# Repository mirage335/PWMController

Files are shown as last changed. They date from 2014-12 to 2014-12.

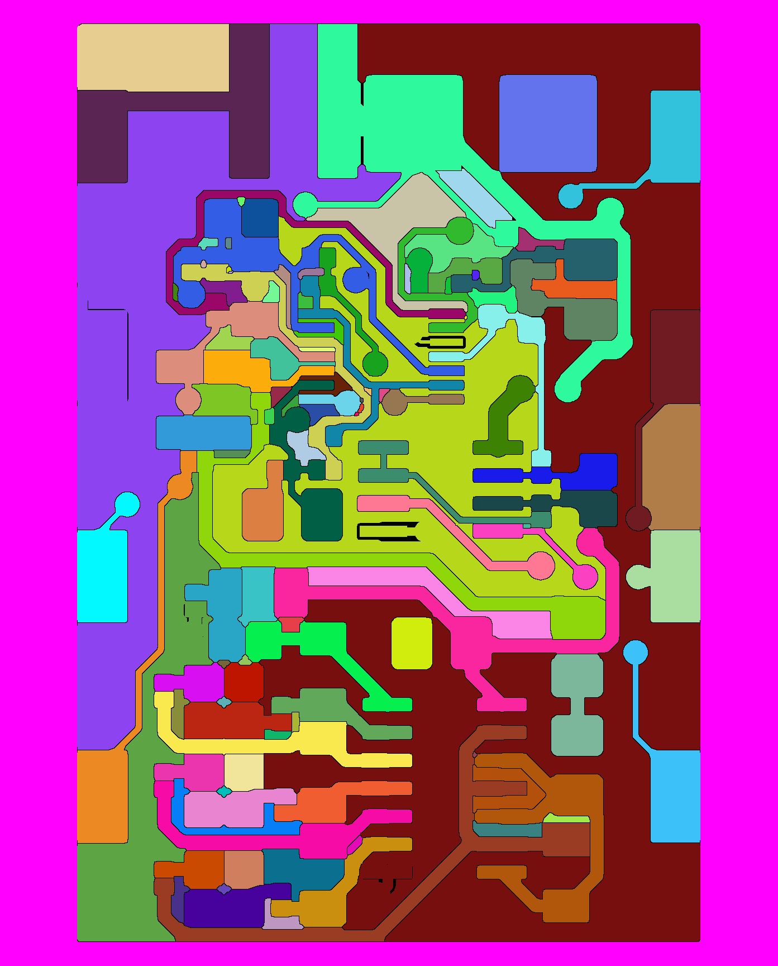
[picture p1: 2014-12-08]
productionStatic/hacdcCNC/PWMController/outp7_traced.png

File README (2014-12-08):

Copyright (C) 2014 mirage335
See the end of the file for license conditions.
See license.txt for PWMController license conditions.

__Usage__
Generic switching power supply block, with emphasis on low EMI. Capable of self-bootstrapping, may be used to generate control voltages for MOSFETS, IGBTs, and similar devices. In some situations, particularly with a linear regulator, may be directly suitable as a generic power supply.

Top-level schematic and PCB layout form a dedicated PCB module, which may be surface-mount soldered directly to the pads defined in the subcircuit. Subcircuit may be integrated into other systems, where individual components or entire module may be soldered in place.

__Design__
Spread-spectrum low-frequency (~5kHz default) switching power supply regulator. Modulation has been carefully characterized to minimize narrowband interference. Duty cycle is limited to permit flyback converter use.

USA companies provide all parts in these schematics.

__Safety__

__Copyright__
This file is part of PWMController.

PWMController is free software: you can redistribute it and/or modify
it under the terms of the GNU General Public License as published by
the Free Software Foundation, either version 3 of the License, or
(at your option) any later version.

PWMController is distributed in the hope that it will be useful,
but WITHOUT ANY WARRANTY; without even the implied warranty of
MERCHANTABILITY or FITNESS FOR A PARTICULAR PURPOSE.  See the
GNU General Public License for more details.

You should have received a copy of the GNU General Public License
along with PWMController.  If not, see <http://www.gnu.org/licenses/>.

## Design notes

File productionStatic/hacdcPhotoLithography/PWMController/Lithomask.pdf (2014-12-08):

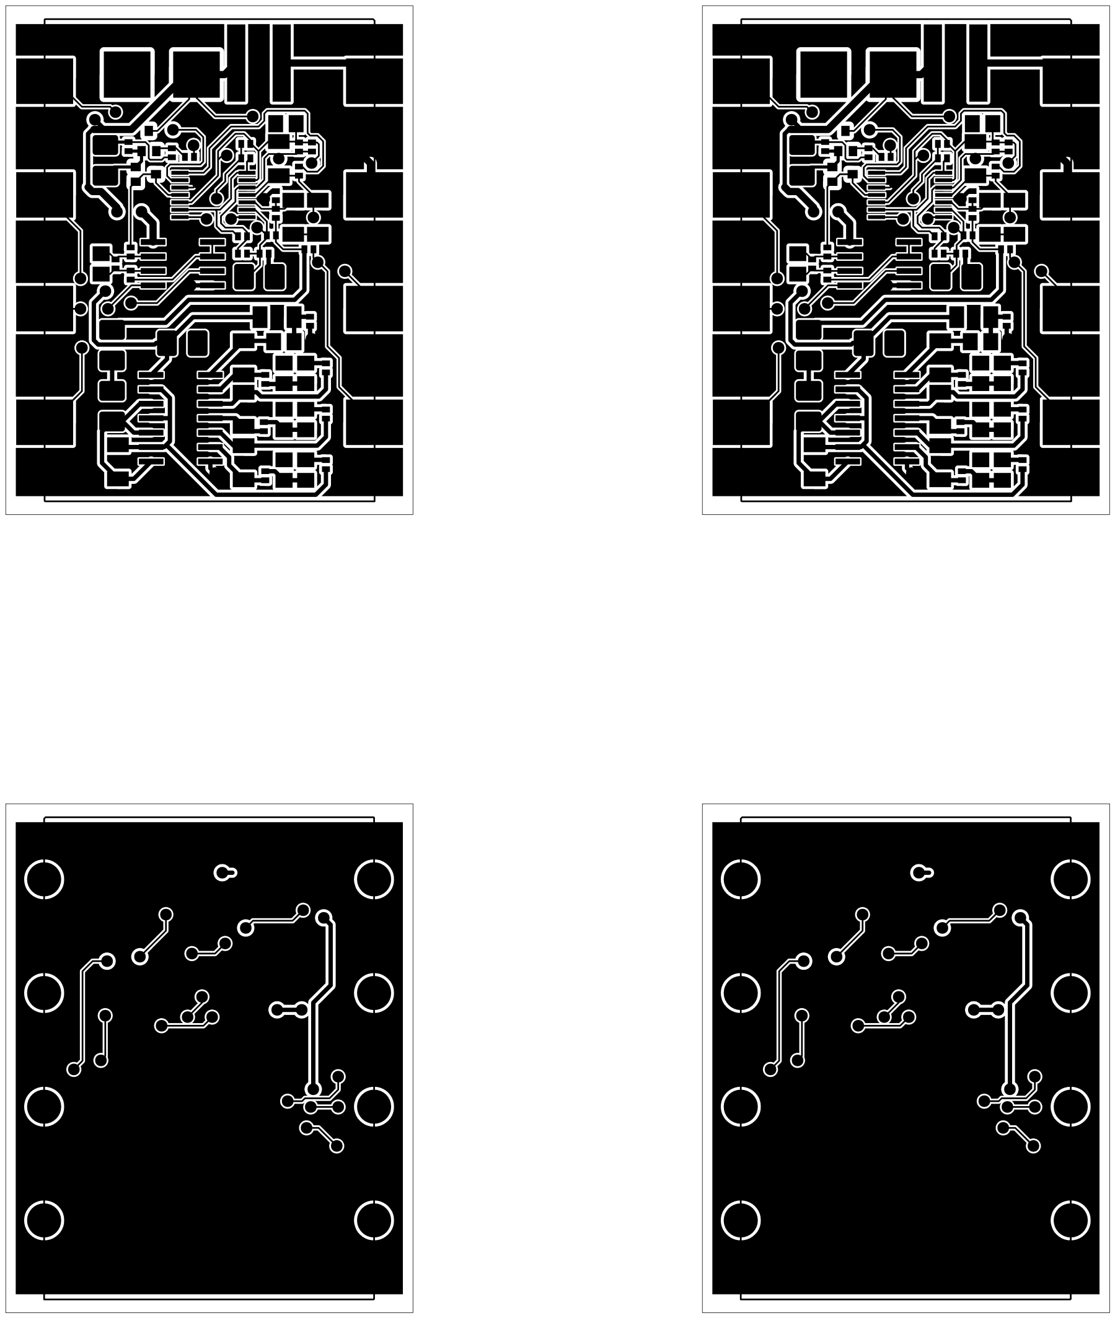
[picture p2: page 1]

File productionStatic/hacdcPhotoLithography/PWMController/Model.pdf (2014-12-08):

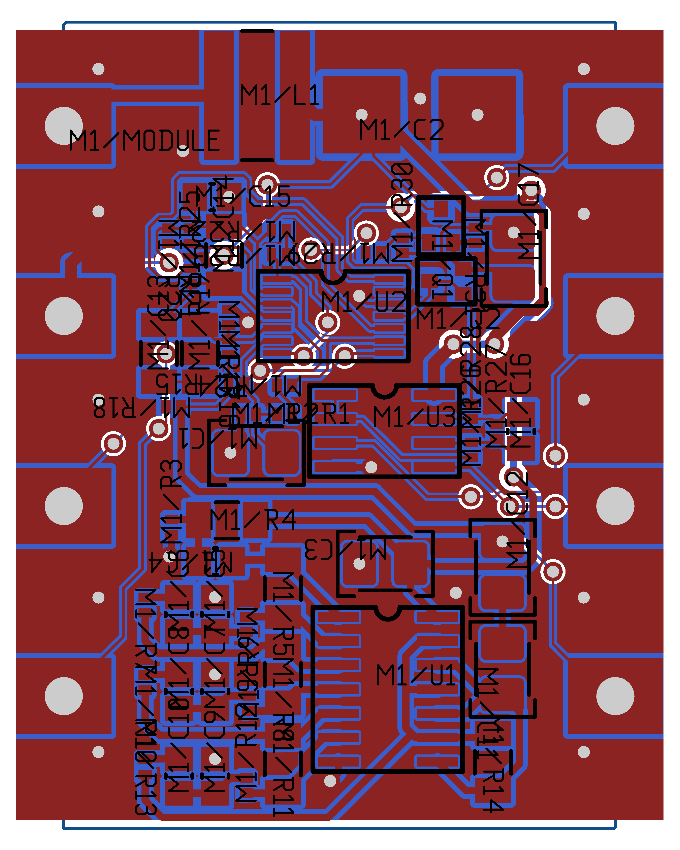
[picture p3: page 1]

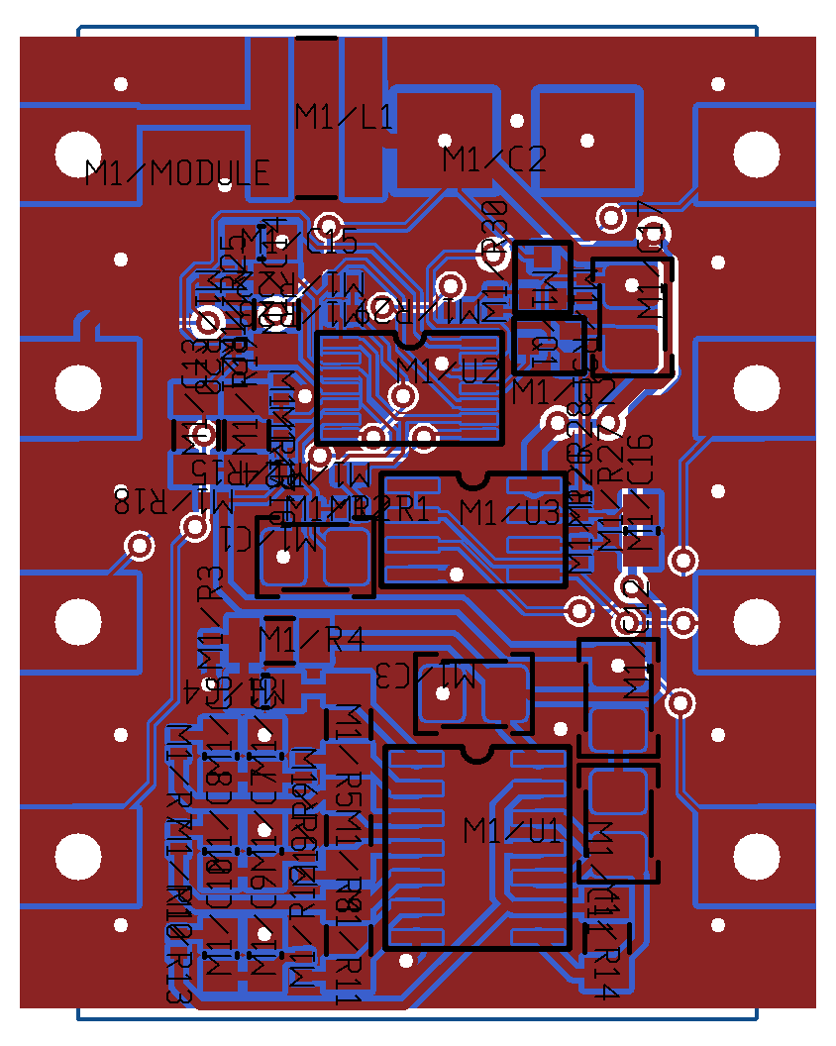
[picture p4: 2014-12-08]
productionStatic/cad/PWMController/Render.png

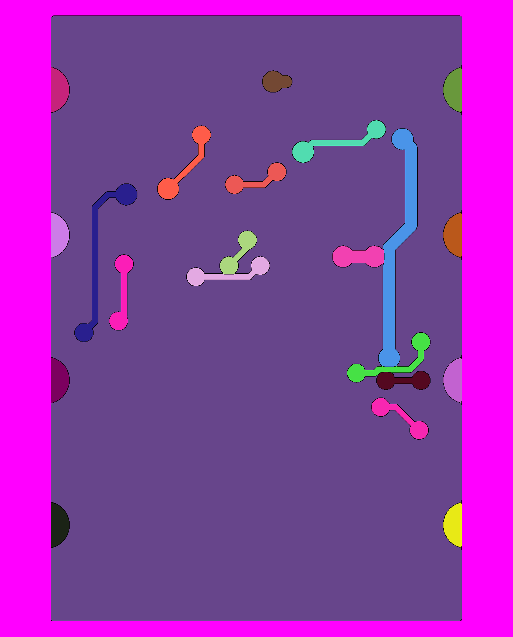
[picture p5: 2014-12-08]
productionStatic/hacdcCNC/PWMController/outp6_traced.png

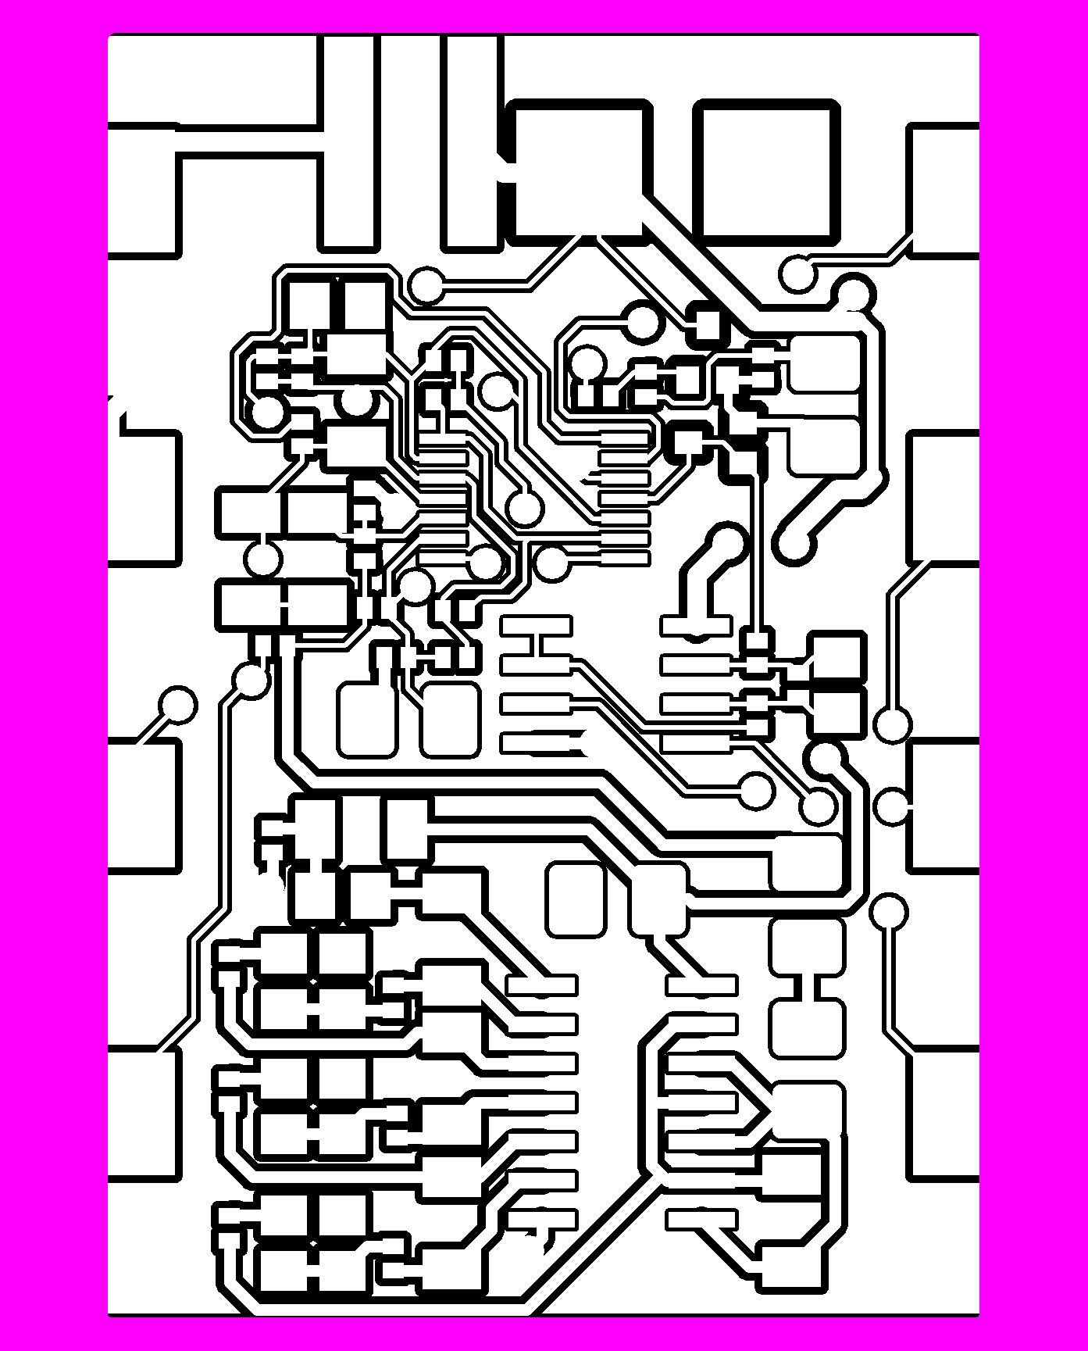
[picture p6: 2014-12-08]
productionStatic/hacdcCNC/PWMController/outp5_masked.png

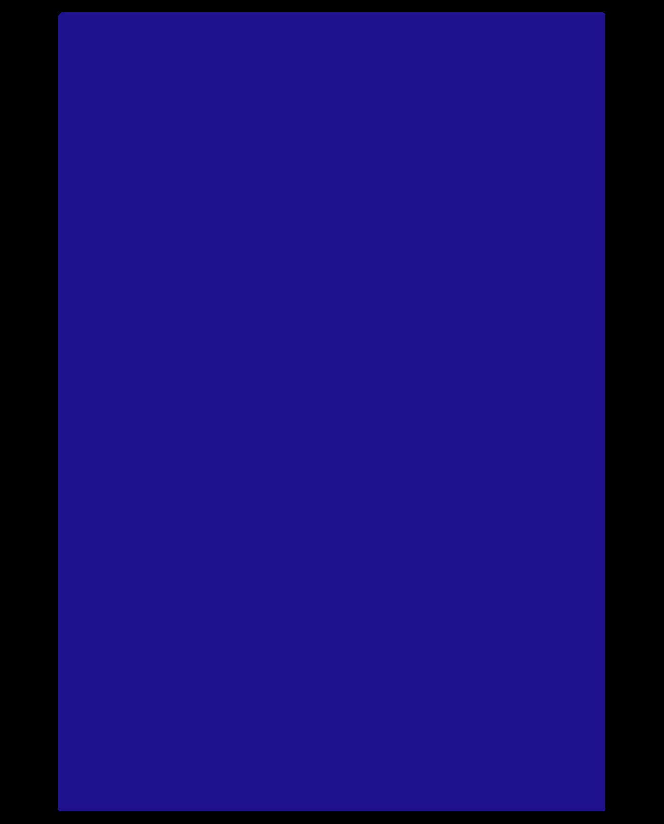
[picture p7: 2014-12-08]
productionStatic/hacdcCNC/PWMController/outp8_traced.png

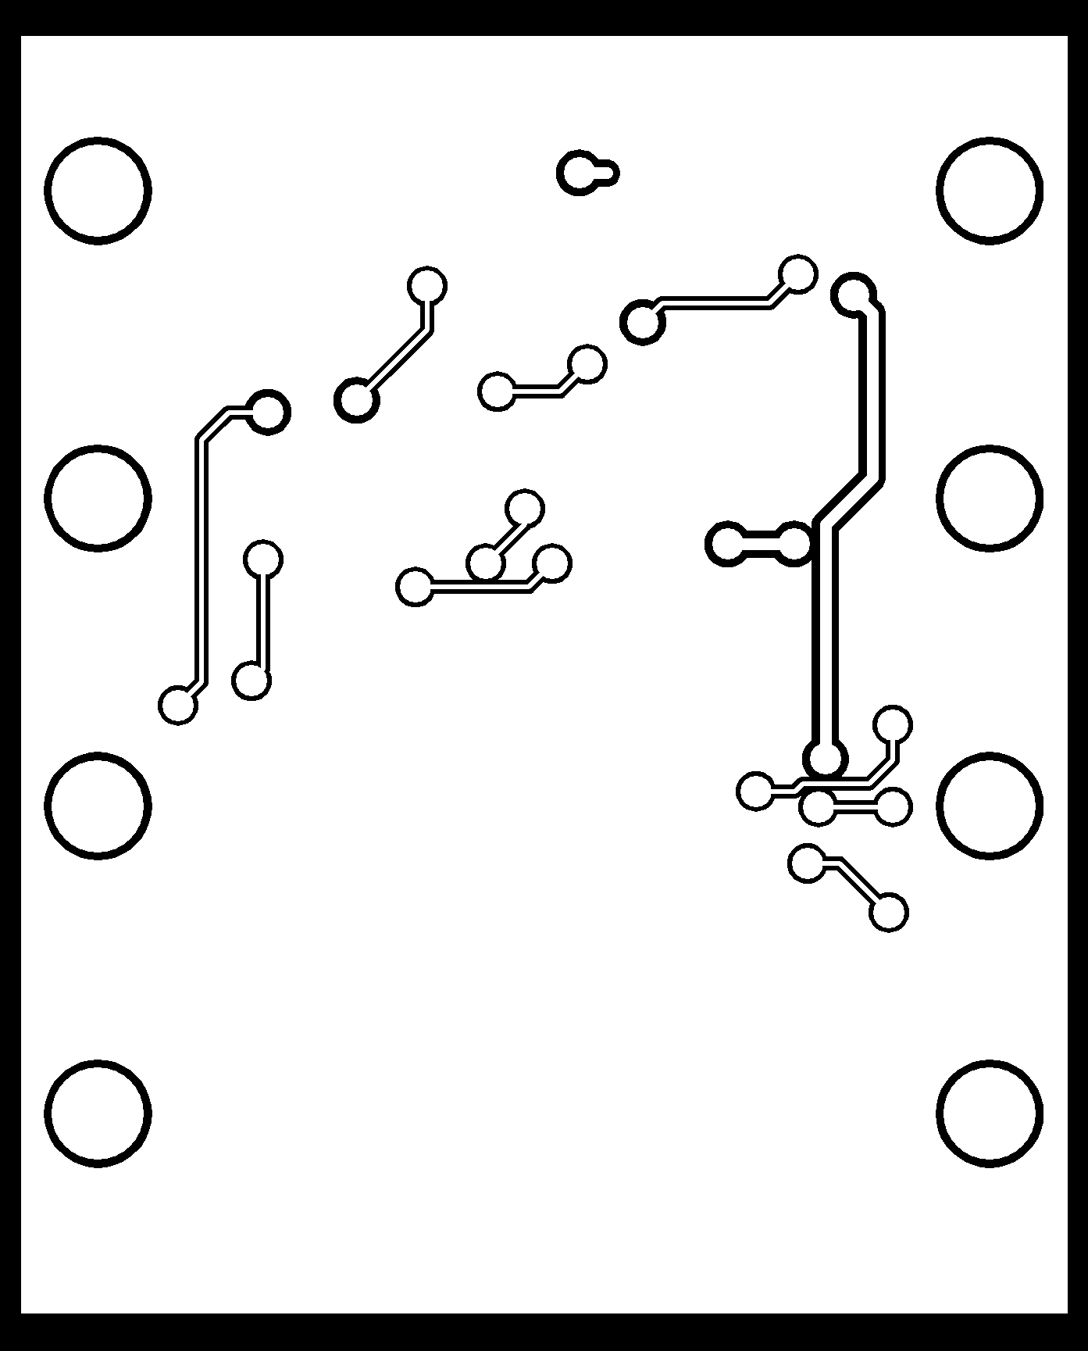
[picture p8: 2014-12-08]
productionStatic/hacdcCNC/PWMController/outp0_original_back.png

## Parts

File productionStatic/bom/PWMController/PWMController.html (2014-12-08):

refdes | device | value | footprint | description | qty
M1/C14 | CAPACITOR | 500p | 1206 | $0.06 MOUSER 77-VJ1206Y471KXAPBC | 1
M1/U2 | TLV1704 | - | TSSOP14 | $2.79 MOUSER 595-TLV1704AIPWR | 1
M1/C13 | CAPACITOR | 0.1u | 1206 | $0.06 MOUSER 77-VJ1206Y104KXJPBC | 1
M1/R19 | RESISTOR | 16 | 1206 | $0.08 MOUSER 71-CRCW1206J-16-E3 | 1
M1/R1,M1/R15,M1/R2,M1/R20,M1/R21,M1/R24 | RESISTOR | 10k | 0402 | $0.13 MOUSER 71-TNPW040210K0DETD | 6
M1/U1 | 4069 | - | SO14 | $0.50 MOUSER 511-4069UBM-TR | 1
M1/L1 | INDUCTOR | 560uH | 1825 | $0.33 MOUSER 815-AISM-1812-561K | 1
M1/R11,M1/R14,M1/R4,M1/R5,M1/R8 | RESISTOR | 10M | 1206 | $0.07 MOUSER 71-RCV120610M0FKEA | 5
M1/U3 | DUAL_OPAMP | - | SO8 | $1.72 MOUSER 595-OPA2170AIDR | 1
M1/R27 | RESISTOR | 1M | 0402 | $0.14 MOUSER 594-MCS04020C1004FE0 | 1
M1/R10,M1/R12,M1/R13,M1/R18,M1/R23,M1/R26,M1/R28,M1/R3,M1/R30,M1/R6,M1/R7,M1/R9 | RESISTOR | 100k | 0402 | $0.14 MOUSER 594-MCS04020C1003FE0 | 12
M1/R29 | RESISTOR | 1k | 0402 | $0.14 MOUSER 594-MCS0402MC1001FE0 | 1
M1/R16,M1/R17,M1/R22,M1/R25,M1/R31 | RESISTOR | 50k | 0402 | $0.08 MOUSER 71-CRCW0402-49.9K-E3 | 5
M1/Q1,M1/Q2 | 2PC4081 | - | SC70_3 | $0.05 MOUSER 771-2PC4081R-T/R | 2
M1/C15,M1/C5,M1/C7,M1/C9 | CAPACITOR | 15n | 0805 | $0.06 MOUSER 77-VJ0805Y153JXACBC | 4
M1/C10,M1/C16,M1/C4,M1/C6,M1/C8 | CAPACITOR | 1.5n | 0805 | $0.06 MOUSER 77-VJ0805Y152JXACBC | 5
M1/C2 | POLARIZED_CAPACITOR | 4.7u | smt2416.ele | $0.61 MOUSER 74-293D475X9035C8T | 1
M1/C1,M1/C11,M1/C12,M1/C17,M1/C3 | POLARIZED_CAPACITOR | 1u | 1411 | $0.34 MOUSER 74-293D105X9050B2TE3 | 5
M1/MODULE | MODULE | - | PWMController-sys | - | 1

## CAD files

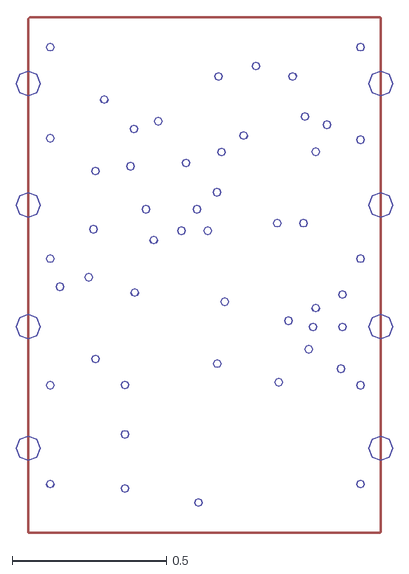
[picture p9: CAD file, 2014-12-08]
productionStatic/cad/PWMController/combined.dxf
1.22 x 1.68

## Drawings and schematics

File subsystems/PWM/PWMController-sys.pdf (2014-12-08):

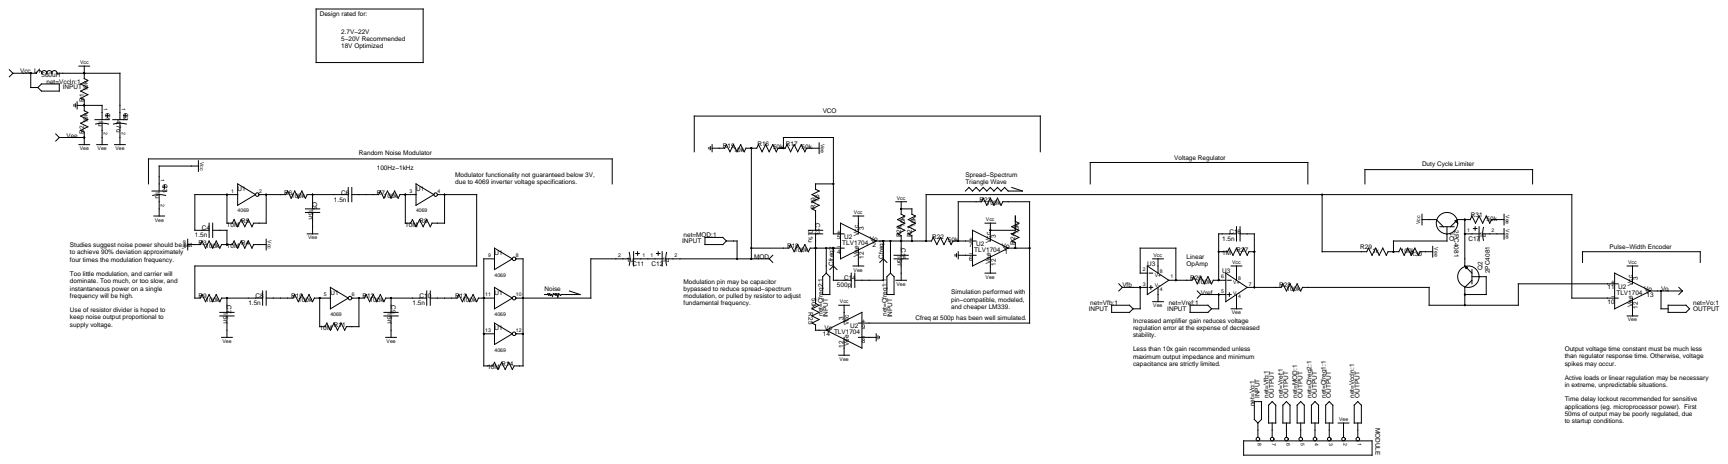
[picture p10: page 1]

Modulator functionality not guaranteed below 3V,
due to 4069 inverter voltage specifications.

Studies suggest noise power should be set
to achieve 90% deviation approximately
four times the modulation frequency.

Too little modulation, and carrier will
dominate. Too much, or too slow, and
instantaneous power on a single
frequency will be high.

Modulation pin may be capacitor
bypassed to reduce spread−spectrum
modulation, or pulled by resistor to adjust
fundamental frequency.

Use of resistor divider is hoped to
keep noise output proportional to
supply voltage.

Cfreq at 500p has been well simulated.

Increased amplifier gain reduces voltage
regulation error at the expense of decreased
stability.

Less than 10x gain recommended unless
maximum output impedance and minimum
capacitance are strictly limited.

Output voltage time constant must be much less
than regulator response time. Otherwise, voltage
spikes may occur.

Active loads or linear regulation may be necessary
in extreme, unpredictable situations.

Time delay lockout recommended for sensitive
applications (eg. microprocessor power). First
50ms of output may be poorly regulated, due
to startup conditions.
